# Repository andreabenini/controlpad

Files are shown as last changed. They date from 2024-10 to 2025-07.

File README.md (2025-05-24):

# controlpad
## ESP32 controller for small robots and general appliances
<div align="center">
  <picture>
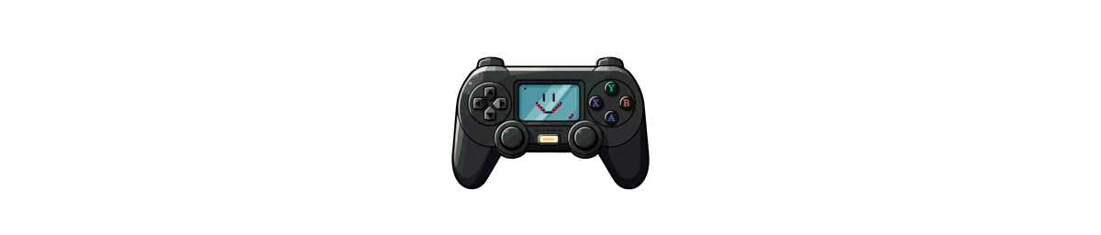
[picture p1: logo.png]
Linux Logo
    
  </picture><br>
All purpose robot and appliance controller
</div>

### _under development_
Project under development with C and ESP-IDF framework, I am uploading latest code
but it still has to be marked as effective alpha version.

### General Features
- PS5 button layout (same size too, effectively a new device in a PS5 shell)  
  16 buttons and two analog joysticks. ESP32C3 core and I2C I/O Expander
- Multi host profile selection to manage multiple appliances
- Embedded display with status information, profile selection, diagnostics
- Configuration update with simple yaml files, firmware flashing with ESP32 utils
- Desktop configuration and upload utility for managing the device
- Macro mapping to single keys or actions with intuitive .yaml files
- LiPo battery, high capacity, durable, rechargeable
- Smartphone stand for independent video stream from the device (if any)

### Communication
- ESP Now
- Bluetooth
- Bluetooth LE
- WiFi (TCP/UDP)

ESP32C3 provides multiple radio options, each single profile can use its preferred
communication method even if for ESP32 based home robots ESP-Now is probably the
suggested method when power consumption, long distance and reliability are taken in
place. Meanwhile TCP and UDP are probably more common for other embedded boards
(RPi devices for example) or generic PCs while Bluetooth for generic embedded
appliances

### TODO List
- (-) 3D STL files definition for inner components (WiP)
- (-) WiP on: hardware, electronics, software (CLI util and builtin firmware)
- (x) ESP32 framework, project and general setup
- (x) Finite state machine and controller endless loop, status definition
- (x) Loading/Uploading configurations from USB (dedicated python utility on desktop)
- (-) Display management, profiles selection, wifi connection, utility menu, hw checkers
- (-) Configuration profiles, yaml parser, networking setup, sending keystrokes to remote
- (-) Troubleshooting, test units, network stress tests
- ( ) Electronics assembly
- ( ) Final HW assembly. 3D printed internals, electronics, I/O devices
- ( ) Final tests on firmware v1.0 and overall tests with different testbeds (PC,
      Generic ESP32, Atmel, RPi devices)

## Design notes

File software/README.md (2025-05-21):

# _ControlPad_
Gamepad controller for dealing with robots, computers, IT networked devices

| Supported Targets | ESP32 | ESP32-C2 | ESP32-C3 | ESP32-C6 | ESP32-H2 | ESP32-P4 | ESP32-S2 | ESP32-S3 |
| --- | ----- | --- | --- | --- | --- | --- | --- | --- |
| | | | X | | | | | |

## How to use it
No particular setup or configuration needed, just flash it into the device and you're done

## Folder contents
The project **controlpad** contains source files in C language,
below is short explanation of the files in the project folder.

```
├── CMakeLists.txt
├── main
│   ├── CMakeLists.txt
│   └── main.c
└── README.md                  This is the file you are currently reading
```

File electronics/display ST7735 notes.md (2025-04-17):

## Display pins

1. **LED** Backlight control pin. Typically, applying a voltage (often the same as VCC)
    turns on the backlight. You might need a current-limiting resistor.
2. **SCK** Serial Clock. Clock signal for SPI communication, generated by your microcontroller.
3. **SDA** Serial Data In / Master Out Slave In (MOSI). Data line for SPI communication
    (data sent from your microcontroller to the LCD).
4. **A0** Data/Command Select (also often labeled DC). Controls whether the data sent is a 
    command or pixel data. High for data, low for command.
5. **RESET** Reset pin. Active low. Used to hardware reset the LCD.
6. **CS** Chip Select. Active low. Used to enable communication with the LCD.
7. **GND** Ground pin. Connect to the ground of your microcontroller.
8. **VCC** Power supply pin. Typically accepts 3.3V or 5V. Crucially, check your module's
    specifications for the correct voltage.

## General considerations
Key Differences from the Generic Pinout:
- LED is the first pin: This confirms the presence of a dedicated backlight control pin.
- Order of SPI and Control Pins: The order of SCK, SDA, A0, RESET, and CS is different from the
    more generic example. You must follow this specific order when connecting to your microcontroller.
- GND and VCC at the end: This is just the physical arrangement of the pins on your module.

Next Steps with this Specific Pinout:
- Backlight Control (LED): To control the brightness or turn the backlight on/off, 
    you'll connect this pin to a digital output pin on your microcontroller. You might need to
    include a current-limiting resistor in series with this pin to prevent damage to the LED.
    The required resistor value depends on the LED's forward voltage and current rating, as well
    as the voltage you are supplying. If you simply want the backlight on all the time, you can
    connect this pin directly to VCC (again, possibly with a resistor).
- SPI Connections (SCK, SDA, CS): Connect these pins to the corresponding SPI pins on your
    microcontroller. Remember that SDA on the LCD module corresponds to the MOSI (Master Out Slave
    In) pin on your microcontroller.
- Data/Command Select (A0): Connect this to a digital output pin on your microcontroller.
- Reset (RESET): Connect this to a digital output pin on your microcontroller. You will typically
    pull this pin high during normal operation and pull it low briefly to reset the display.
- Ground (GND): Connect this to the ground pin of your microcontroller.
- Power (VCC): Connect this to the appropriate power supply voltage (3.3V or 5V, depending on your
    module's specification). Double-check the voltage requirements!

## Display to ESP32C3 Connection
| LCD Pin | ESP32-C3 Mini Pin | ESP32-C3 GPIO | Description | Notes
|---|---|---|---|---
| LED | VCC | - | Backlight (Always On) | check resistor, should be 220
| SCK | SCK | GPIO4 | SPI Clock |
| SDA | MOSI | GPIO6 | SPI Data In | MOSI
| A0 | - | GPIO5 | Data/Command Select | control pin from GPIO5
| RESET | - | GPIO10 | Reset | control pin from GPIO10
| CS | SS | GPIO7 | Chip Select | control pin from GPIO7
| GND | GND | GND | Ground | connect to a common ground
| VCC | 3.3V | VCC (on ESP32)| Power Supply|

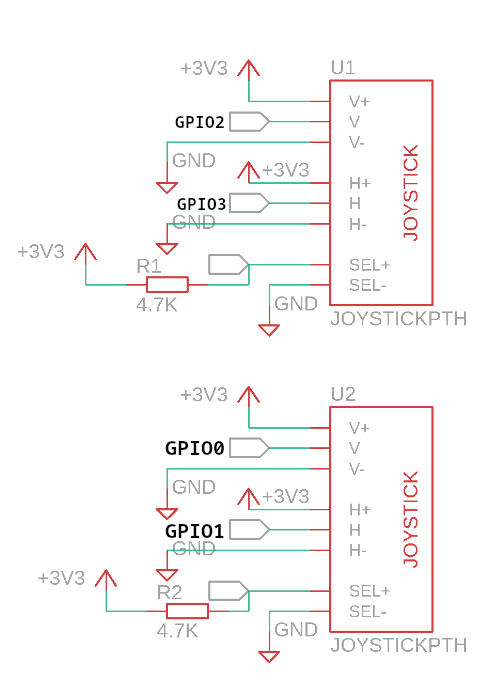
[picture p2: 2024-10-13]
electronics/joystick.png

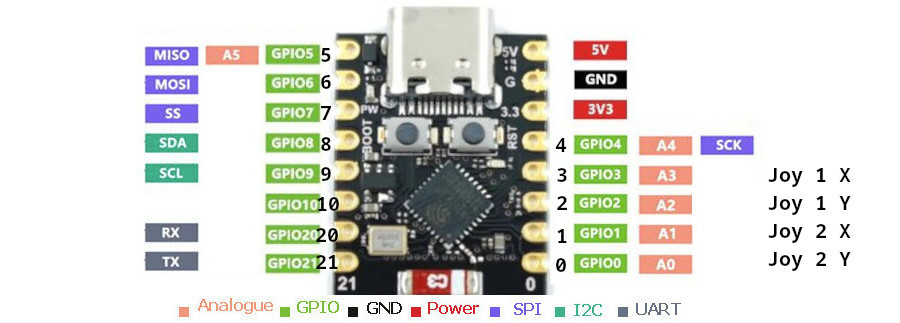
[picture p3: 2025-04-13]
electronics/esp32c3 pinout.jpg

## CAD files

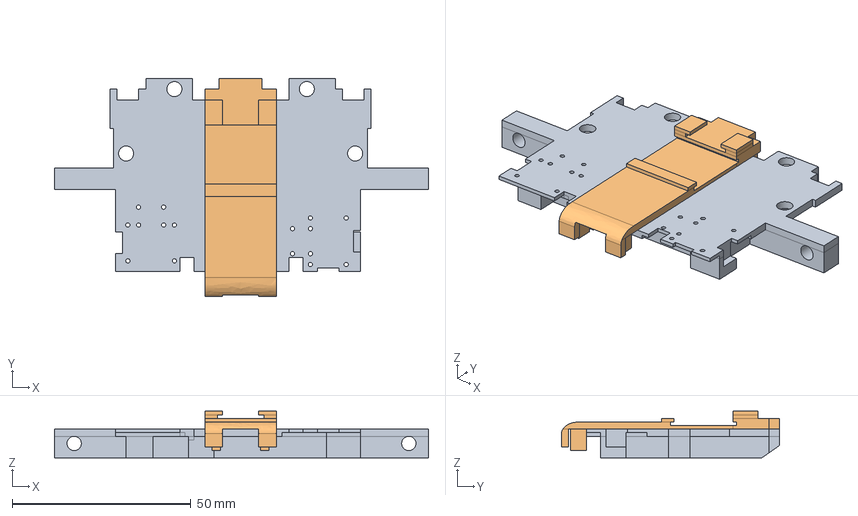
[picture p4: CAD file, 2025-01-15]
hardware/controlpad.FCStd
104.5 x 61.0 x 13.0 mm
battery holder
USB-C holder

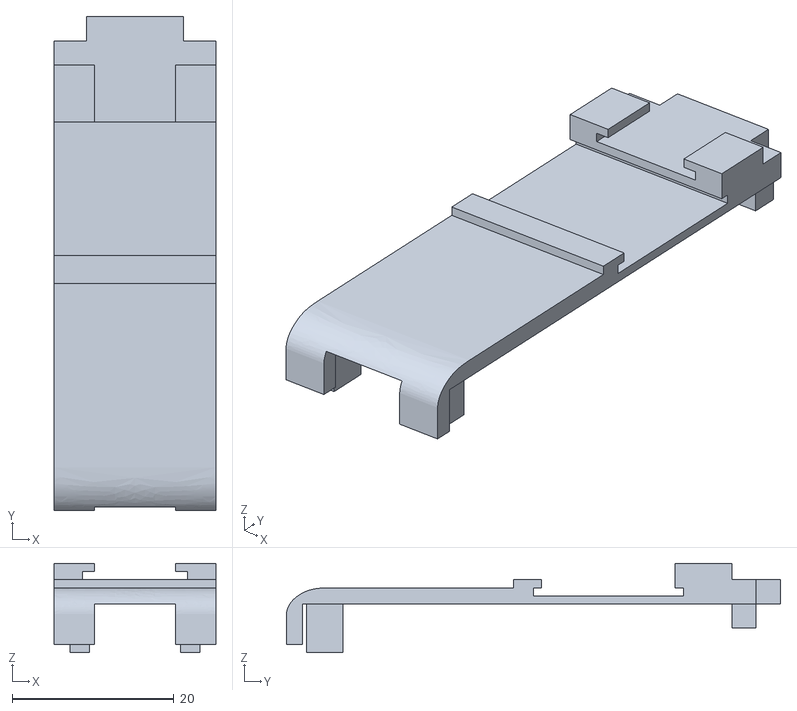
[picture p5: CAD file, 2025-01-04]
hardware/controlpad-USB-C holder.stl
20.0 x 61.0 x 11.0

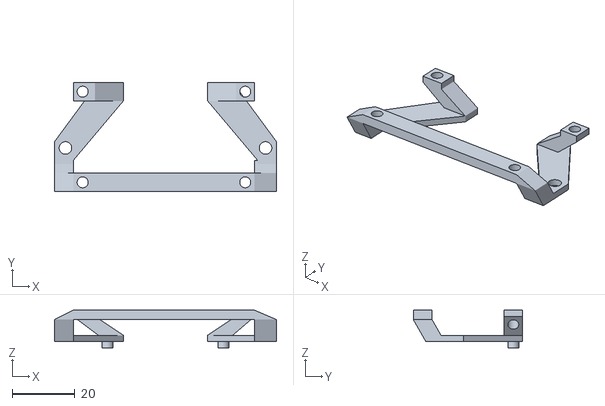
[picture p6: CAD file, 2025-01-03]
hardware/controlpad-display bracket.stl
71.0 x 35.0 x 12.0

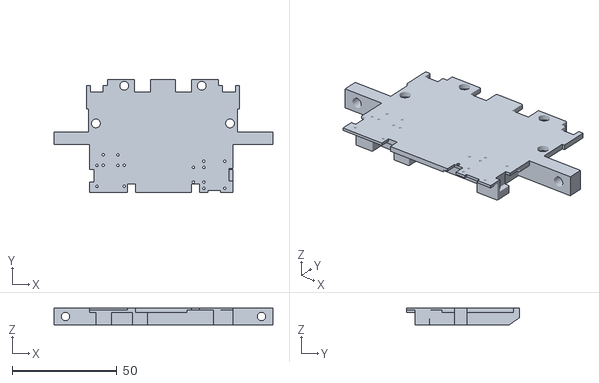
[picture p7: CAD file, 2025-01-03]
hardware/controlpad-battery holder.stl
104.5 x 54.0 x 8.00

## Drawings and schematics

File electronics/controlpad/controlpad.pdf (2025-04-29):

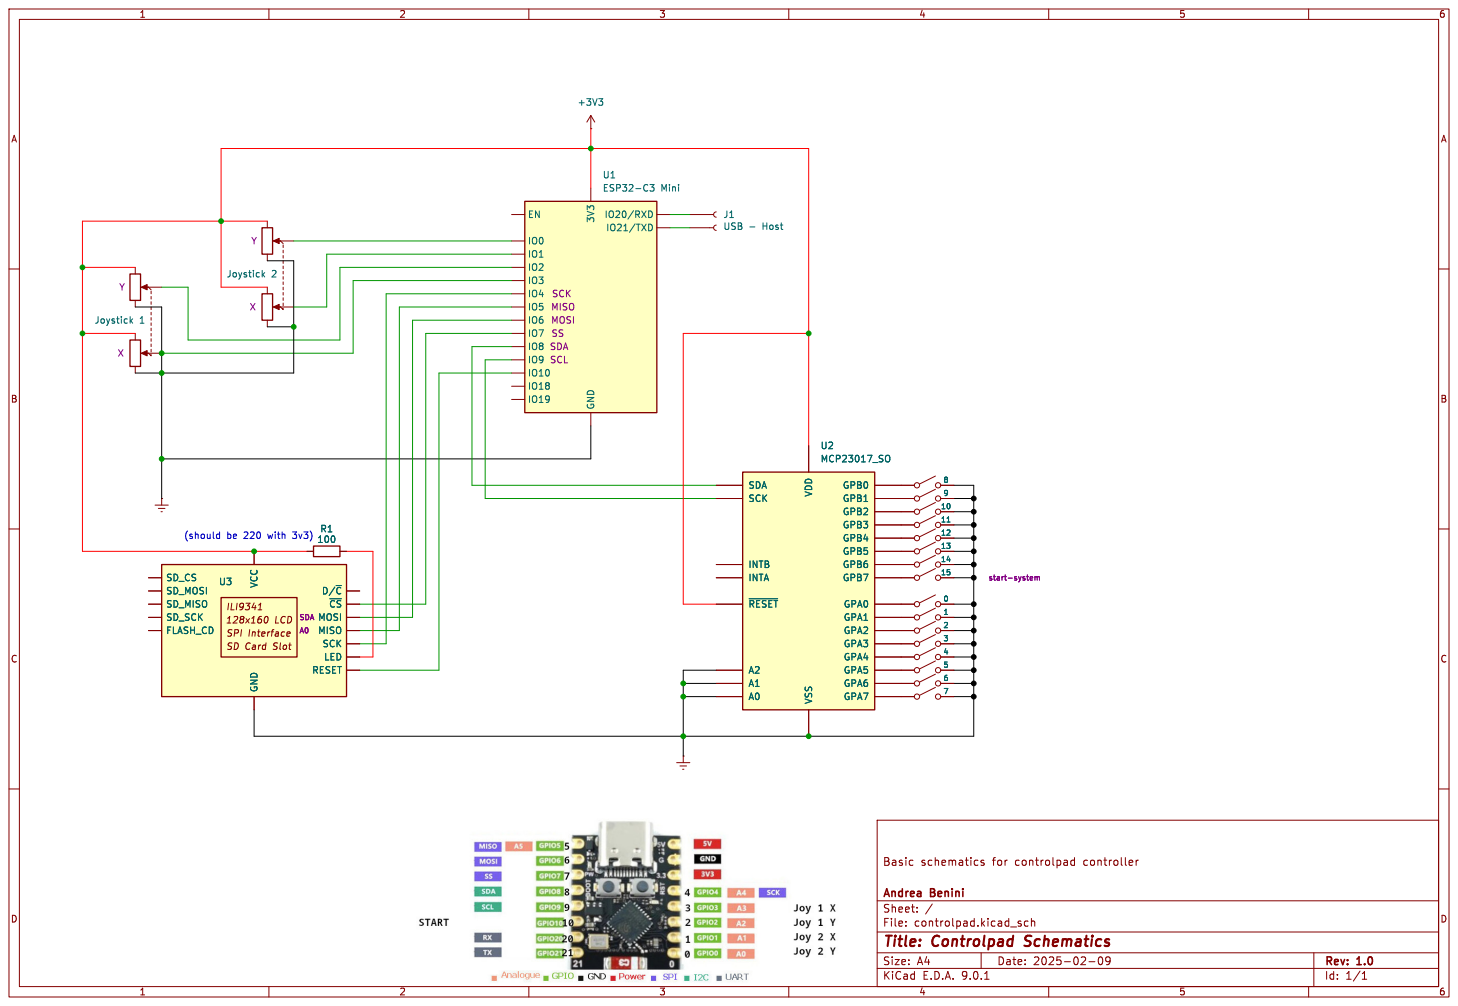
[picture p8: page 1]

SCL SCK MISO MOSI SS

Id: 1/1 Title: Controlpad Schematics

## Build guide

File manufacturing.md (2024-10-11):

# PS5 Board Specs

## Controller Dimensions
- Blender pieces:
    - Top    : 3153 x 2083 x 931 [X,Y,Z]
    - Bottom : 3118 x 2102 x 956 [X,Y,Z]
- Real life dimensions: 160mm x 106mm x 66mm [X,Y,Z]

## Files setup
- Test 1 (now printing)
    - Blender export (x100 factor)
    - Cura resize, 50.75%
- Test 2, correct scale
    - Blender export (x100 factor)
    - Cura resize, 53.25%. (166.0426, 111.9391, 50.9021) [X,Y,Z]
- Test 3, correct scale
    - Blender export (x100 factor)
    - Cura resize, 55%. (171.4994, 115.6178, 52.5749) [X,Y,Z]
- Test 4, scale fix with a reference
    - Blender export (Selection only, Scale 1.0, No scene unit, apply modifiers)
    - Cura resize, 10000%

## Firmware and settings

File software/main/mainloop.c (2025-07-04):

#include "mainloop.h"
#include "freertos/projdefs.h"
#include "i2c.h"
#include "joystick.h"
#include "fsm.h"
#include "configuration.h"



keyboardStatus keyboard = {0};
extern QueueHandle_t  queueMessage;


/**
 * buttonRead - Collect button events from I2C
 * @param gpioA_data (uint8_t) GPIO-A register from MCP23017
 * @param gpioB_data (uint8_t) GPIO-B register from MCP23017
 * @return (void)
 */
void buttonRead(uint8_t gpioA_data, uint8_t gpioB_data) {
    uint8_t  i;
    bool     stateRaw;
    uint32_t timeCurrent = pdTICKS_TO_MS(xTaskGetTickCount());
    
    // Buttons are connected to ground and pull-ups are enabled,
    // Invert and mask to get pressed states, 0=pressed, 1=not pressed
    gpioA_data = ~gpioA_data;
    gpioB_data = ~gpioB_data;
    // GPIO-A (0-7) Process buttons, if needed
    for (i=0; i<8; i++) {
        stateRaw = (gpioA_data & (1<<i)) > 0;
        // If stateRaw changed from latest reading
        if (stateRaw != keyboard.button[i].stateLastRaw) {
            keyboard.button[i].stateLastRaw   = stateRaw;
            keyboard.button[i].timeLastChange = timeCurrent;
        } else {
            // If enough time has passed since the last change, update the current state
            if ((timeCurrent - keyboard.button[i].timeLastChange >= TIME_DEBOUNCE_BUTTONS) && (keyboard.button[i].stateCurrent != stateRaw)) {
                keyboard.button[i].stateCurrent = stateRaw;
                eventButton(i, stateRaw);
            }
        }
    }
    // GPIO-B (8-15) Process buttons, if needed
    for (i=0; i<8; i++) {
        stateRaw = (gpioB_data & (1<<i)) > 0;
        // If stateRaw changed from latest reading
        if (stateRaw != keyboard.button[i+8].stateLastRaw) {
            keyboard.button[i+8].stateLastRaw   = stateRaw;
            keyboard.button[i+8].timeLastChange = timeCurrent;
    
        } else {
            // If enough time has passed since the last change, update the current state
            if ((timeCurrent - keyboard.button[i+8].timeLastChange >= TIME_DEBOUNCE_BUTTONS) && (keyboard.button[i+8].stateCurrent != stateRaw)) {
                keyboard.button[i+8].stateCurrent = stateRaw;
                eventButton(i+8, stateRaw);
            }
        }
    }
} /**/


/**
 * Main task function for keyboard management
 */
void taskMainLoop(void *pvParameter) {
    ESP_LOGI(TAG_MAINLOOP, "Task created");
    esp_err_t               err;
    adc_channel_t           channel[4] = {JOYSTICK1_X, JOYSTICK1_Y, JOYSTICK2_X, JOYSTICK2_Y};
    adc_continuous_handle_t adcHandle = NULL;
    uint32_t                adcResultNum = 0;               // Continuous read returned bytes
    uint8_t                 adcData[ADC_BUFFER_SIZE] = {0}; // Continuous read adc data stream
    adc_digi_output_data_t  *p;                             // data stream pointer
    i2c_master_bus_handle_t handleBus;
    i2c_master_dev_handle_t handleDevice;
    // Init ADC on axes
    err = joystickInit(&channel, &adcHandle);
    if (err != ESP_OK) {
        ESP_LOGE(TAG_MAINLOOP, "Failed to initialize joystick configuration (%d)", err);
        vTaskDelete(NULL);
        return;
    }
    // I2C
    err = i2c_MasterInit(&handleBus, &handleDevice);
    if (err != ESP_OK) {
        ESP_LOGE(TAG_MAINLOOP, "Failed to initialize I2C Master");
        vTaskDelete(NULL);
        return;
    }
    // Initialize buttons on I2C gpio extender
    err = mcp23017_Init(handleDevice);
    if (err != ESP_OK) {
        ESP_LOGE(TAG_MAINLOOP, "Failed to initialize I2C buttons (0x%04X), check I2C connections, program aborted", err);
        i2c_master_bus_rm_device(handleDevice);
        i2c_del_master_bus(handleBus);
        vTaskDelete(NULL);
        return;
    }

    // [[LOOP]] // Read controller status, endless loop for the task
    uint8_t gpioA_data, gpioB_data;
    if (configurationInitialize() != ESP_OK) {
        ESP_LOGE(TAG_MAINLOOP, "Failed to load configuration from the memory");
        i2c_master_bus_rm_device(handleDevice);
        i2c_del_master_bus(handleBus);
        vTaskDelete(NULL);
        return;
    }
    if (statusInit() != ESP_OK) {
        ESP_LOGE(TAG_MAINLOOP, "Failed to initialize FSM statusInit()");
        i2c_master_bus_rm_device(handleDevice);
        i2c_del_master_bus(handleBus);
        vTaskDelete(NULL);
        return;
    }
    uint32_t   receivedSignal;
    BaseType_t receivedQueue;
    while (1) {
        // Read input from I2C, Register A
        err = mcp23017_RegisterRead(handleDevice, MCP23017_GPIOA, &gpioA_data);
        if (err != ESP_OK) {
            ESP_LOGE(TAG_MAINLOOP, "Failed to read GPIO buttons, Register A");
            // Clean up before returning
            i2c_master_bus_rm_device(handleDevice);
            i2c_del_master_bus(handleBus);
            vTaskDelete(NULL);
            return;
        }
        // Read input from I2C, Register B
        err = mcp23017_RegisterRead(handleDevice, MCP23017_GPIOB, &gpioB_data);
        if (err != ESP_OK) {
            ESP_LOGE(TAG_MAINLOOP, "Failed to read GPIO buttons, Register B");
            // Clean up before returning
            i2c_master_bus_rm_device(handleDevice);
            i2c_del_master_bus(handleBus);
            vTaskDelete(NULL);
            return;
        }
        // Read analog values from all joystick axes
        err = adc_continuous_read(adcHandle, adcData, ADC_BUFFER_SIZE, &adcResultNum, 0);
        if (err == ESP_OK) {
            for (int i=0; i<adcResultNum; i+=SOC_ADC_DIGI_RESULT_BYTES) {
                p = (adc_digi_output_data_t*)&adcData[i];
                // Check the channel number validation, the data is invalid if the channel num exceed the maximum channel
                switch (ADC_GET_CHANNEL(p)) {
                    case 0:
                        keyboard.joystick1_X = ADC_GET_DATA(p);
                        break;
                    case 1:
                        keyboard.joystick1_Y = ADC_GET_DATA(p);
                        break;
                    case 2:
                        keyboard.joystick2_X = ADC_GET_DATA(p);
                        break;
                    case 3:
                        keyboard.joystick2_Y = ADC_GET_DATA(p);
                        break;
                }
            }
        } else if (err == ESP_ERR_TIMEOUT) {
            // Try to read `ADC_BUFFER_SIZE` until API returns timeout, which means there's no available data. Usually "break;"
            ESP_LOGW(TAG_MAINLOOP, "ADC Continuous read timeout");
        }

        // Read button functions and trigger events
        buttonRead(gpioA_data, gpioB_data);             // Read buttons and raise events, if any
        eventStatus();                                  // Raise event to report overall system state
        /**
         * Because printing is slow every time `ulTaskNotifyTake` is called it will immediately return.
         * To avoid a task watchdog timeout, adding a delay here. When you replace the way you process the data,
         * usually you don't need this delay (as this task will block for a while).
         */
        // FIXME: Comment it back again once done or debugging has been restored
        // ulTaskNotifyTake(pdTRUE, portMAX_DELAY);        // Adding it to avoid task's watchdog timeout (see note above)
        // Non-blocking check for item in the queue from Task2 (loading new configuration from serial port)
        receivedQueue = xQueueReceive(
            queueMessage,                               // The queue to receive from
            &receivedSignal,                            // Pointer to where received data will be stored
            0                                           // Don't wait (non-blocking)
        );
        if (receivedQueue == pdTRUE) {
            statusChange(STATUS_CONFIGURATION);
        }
        // FIXME: Here comes the mess, I cannot reach next '+.+' debug point
        // ulTaskNotifyTake(pdTRUE, portMAX_DELAY);        // Adding it to avoid task's watchdog timeout (see note above)
        if (ulTaskNotifyTake(pdTRUE, pdMS_TO_TICKS(1000)) == 0) {
            ESP_LOGW(TAG_MAINLOOP, "notification timeout");
        }
        vTaskDelay(pdMS_TO_TICKS(TIME_POLL_DELAY));     // POLL_DELAY between reads (as .h define)
    }
    // Clean up
    // TODO: Add these two in every exit condition or rearrange exit cleanly
    ESP_ERROR_CHECK(adc_continuous_stop(adcHandle));
    ESP_ERROR_CHECK(adc_continuous_deinit(adcHandle));

    i2c_master_bus_rm_device(handleDevice);
    i2c_del_master_bus(handleBus);
    ESP_LOGI(TAG_MAINLOOP, "I2C bus closed");
    ESP_LOGI(TAG_MAINLOOP, "Task closed");
    vTaskDelete(NULL);                                  // Delete the task, without this I'm getting a guru meditation error with core0 in panic mode
} /**/

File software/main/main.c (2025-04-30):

// Program Includes
#include "main.h"
#include "mainloop.h"
#include "serial.h"


// System includes
#include <freertos/FreeRTOS.h>              // IWYU pragma: keep
#include <freertos/task.h>
#include <esp_log.h>
#include <esp_system.h>
#include <string.h>


QueueHandle_t queueMessage;



void app_main(void) {
    ESP_LOGW(TAG_APP, "Program Started");
    queueMessage = xQueueCreate(1, sizeof(uint32_t));
    if (queueMessage == NULL) {
        ESP_LOGE(TAG_APP, "Cannot create the message queue");
        return;
    }
    // Create the I/O peripherals management task
    //      - taskFunction
    //      - task name for debugging
    //      - stack size
    //      - task parameters
    //      - task priority (lower number = lower priority)
    //      - task handle (optional)
    xTaskCreate(taskMainLoop, "taskLoop",   4096, NULL,  5, NULL);
    // Create serial task for receiving async incoming configurations from console (I've a 10K buffer for data stream in it)
    xTaskCreate(taskSerial,   "taskSerial", 4096, NULL, 12, NULL);
} /**/

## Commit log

2024-10-11 OpenSCAD lib for perfboards
    [scaboardlib.scad]
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2024-10-13 hiding local wireless config
2024-11-01 Basic tasks, acquiring adc joystick values, sample project
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2024-11-02 adc one shot mode
2024-11-04 adc continous mode reading optimized
2024-11-07 Adding complete gamepad buttons layout
2024-11-07 adding last gpio left on the board as a START button
2024-11-08 keyboard prototype, stub functions with direct ADC readings
2024-11-09 controlpad hw parts
    [controlpad.FCStd]
2024-11-10 Updated USB-C holder to better fit the inner shell
    [controlpad.FCStd]
2024-11-10 rounded shaped to better fill the controlpad inner shell
    [controlpad-USB-C holder.stl]
2024-12-05 Controlpad prototype, main file
2024-12-21 adc continous sample test
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2024-12-26 I2C init total rewrote according to ESP-IDF docs
2024-12-30 Li-Ion battery holder
    [controlpad-battery holder.stl]
2024-12-30 New battery holder with brackets and buttons mount points
    [controlpad-battery holder.stl]
2024-12-30 USB C pcb holder for newest battery case
    [controlpad-USB-C holder.stl]
2025-01-01 Cleaning old 3d models
    [scaboardlib.scad]
2025-01-01 New battery holder with joystick1 support
    [controlpad-battery holder.stl]
2025-01-01 joystick mounting holes have been added, fixing side panel mount with hols
    [controlpad-battery holder.stl]
2025-01-03 Newly improved battery holder with display bracket mounting holes
    [controlpad-battery holder.stl, controlpad-display bracket.stl]
2025-01-04 holder brackets keeps sorted also the PCB-PSU and the power switch
    [controlpad-USB-C holder.stl]
2025-01-15 FR4 is no longer needed, I'm 3d printing all the internal structures too
2025-01-15 New controlpad model, updating battery base and display
    [controlpad.FCStd]
2025-01-17 Dealing with I2C, some tests
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2025-02-08 I2C init, tested and working
2025-02-09 Adding kicad files to project
2025-02-09 kicad files
    [controlpad.kicad_pcb]
2025-02-09 kicad schematics, version 1
    [controlpad.kicad_sch]
2025-02-09 kicad schematics project, version 1
2025-02-09 Reading Sample I2C inputs on GPIO_A
2025-02-11 Adding I/O to I2C expander, clearing few short circuits on joysticks
    [controlpad.kicad_sch]
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2025-02-12 Adding push buttons to GPA
    [controlpad.kicad_sch]
2025-02-13 Updated schematics, adding push buttons on GPA 0..7
2025-02-15 removing crappy and not working I2C code, project cleanup
2025-02-19 Adding ESP32C3 image to the schematics as a reference
    [controlpad.kicad_sch]
2025-02-19 Updating PDF with schematics, adding ESP32C3 real image as a reference
2025-02-19 I2C + MCP 23017 working, 4 inputs on GPIOA
2025-03-25 Updating to kicad 9
    [controlpad.kicad_sch]
2025-03-25 Generating new schematics with 8 I/O from I2C. kicad 9
2025-03-26 Dealing with button debouncing for clean reads
2025-03-26 Adding poll delay between reads and button debounce time for dealing with them
2025-03-26 Switchingg to agressing poll delay -> 10ms (it works)
2025-03-26 Adding to schematics all buttons on GPIO-B (8-15)
    [controlpad.kicad_sch]
2025-03-26 Adding buttons on I2C GPIO-B (8-15)
2025-03-26 controlpad definitions updated
    - Adding 16 buttons on I2C I/O
    - 1 start button controlled directly from the MCU
    - Adding MCP23017 GPIO definitions for GPIOA and GPIOB
    - Refining internal functions prototypes
    - Creating new keyboard status structure
    - Removing old struct
2025-03-29 Adding display to the board
    [controlpad.kicad_sch]
2025-03-30 display 3v3 and gnd
    [controlpad.kicad_sch]
2025-04-02 testing PWM and joysticks on a test bed
2025-04-03 Refining base sample for ADC continuous read
2025-04-07 Crashed on task creation
    [main.c]
2025-04-07 switching back to production code with keyboard task
2025-04-07 keyboard i/o prototype, no refactoring, no optimizations. testing stability
2025-04-13 Connecting ILI9341 to ESP32C3 with SPI
2025-04-13 Using 5 wires to drive the display with SPI
2025-04-13 adding resistor on LED pin
    [controlpad.kicad_sch]
2025-04-13 Removing start button from GPIO10
2025-04-13 Removing start button from GPIO10, now using I2C
    [controlpad.kicad_sch]
2025-04-13 START button on I2C, removing it from GPIO10
2025-04-14 removing start button as direct key
2025-04-16 Adding compatible SPI display ST7735 to the project
2025-04-17 hiding pin numbers on ESP32C3 to avoid unnecessary noise
    [controlpad.kicad_sch]
2025-04-18 Debug tests with sample program for dealing display output
2025-04-19 I2C init for I/O buttons on SDA/SCL
2025-04-22 Fixing new requirements for the project: nvs, adc, gpio
2025-04-22 Finite State Machine, first prototype with menu state
2025-04-22 Adding three state to the FSM: menu, profile, system so I can deal the device
2025-04-24 moving samples to hardware.hacks repository
2025-04-27 NVS memory management functions
    [configuration.h]
2025-04-29 Adding B15 as system/start button
    [controlpad.kicad_sch]
2025-04-30 Basic display functions for managing ST7735 through SPI
2025-05-01 FSM for user interaction with the device (Profile User)
2025-05-03 Serial port management class for loading configuration in the device
2025-05-05 Configuration functions for dealing with: listing, reading, writing and clearing
    [configuration.h]
2025-05-06 Fixing event loop with proper wifi init
    - get back to if/else statements instead of the switch for cleaner code
    - deallocating resources to avoid esp_event_loop_create_default() problem once disconnected
    - moving esp_handlers as static/global on module
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2025-05-13 Debugging around some spurious device connection errors. still working on it
2025-05-21 init with low power, wait, then init with a decent tx power
2025-05-30 Adding bluetooth connection defines
    [configuration.h]
2025-05-30 Documenting parameters
    [configuration.h]
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2025-06-03 Conflicting with object fsm.configuration, renaming to configurationInitialize()
    [configuration.h]
2025-06-07 Adding buttons mapping to the configuration
    [configuration.h]
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
